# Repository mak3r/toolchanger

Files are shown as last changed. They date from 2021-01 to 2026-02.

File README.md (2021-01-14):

# E3D Toolchanger Experience

## Overview

The E3D toolchanger was one of the most excting announcements in the late 20-teens. I had been keeping my eyes on the project for some time as well as having a general interest in Core X/Y printing. 

The E3D Toolchanger is a specification and BOM for a 3D printer which can operate 4 different toolheads. In the past, we have seen dual extruder printers and even multi nozzle extruders. There have also been efforts to create multi filament processors leading to a single tool. These include the Palette and the Prusa MMU2s. My experience with these MMU2s multi filament processor was terrible. There seemed to be no scientific approach to tuning filament extraction which is absolutely necessary to achieve positive results. The Toolchanger does not suffer from this problem.

Since the toolchanger has 4 independent hotends, each one can be managed independently including filament load/unload/wipe/purge/prime operations. While it sounds like it might be 4x the complexity, I assure you it is not. The biggest challenge is tuning filaments but I have found other than using the parameters provided by the vendor - such as a Prusa MK3s with PrusaSlicer configs - the problem is universal.

Multi tool additive manufacturing for the hobbyist also became possible in part because of microprocessor development specifically for the multi-toolhead use case. The Toolchanger uses the Duet and Duex boards from Duet3D. These 32 bit boards have more motor driver capabilities as well as taking advantage of hardware based tool changes. I like this.

## What to expect if you are building a toolchanger

* Poor documentation
    * Steps out of order
    * Limited cleanups/revisions long after an issue has been identified
    * I actually stopped giving credit to the guide authors because the docs were so poorly done. 
    * On the other hand, this would have been impossible without the guides.
* Exactly the parts needed 
    * Sometimes less
* Print your own parts (you NEED another 3D printer to build this one)
* Additional tools required
    * locktite
    * superglue
    * 7mm wrench (nozzle)
    * 16mm slim wrench (tightening V6 nozzles)
    * 12mm slim wrench (putting on feet)
    * 2.5mm tap
    * 3mm tap

# Tips

## Mesh compensation
The system uses the G29 command to run mesh compensation:

* Run mesh compensation 
    
    `G29 S0`
* Save the last mesh comp values in a file called "abc.mesh"
    
    `G29 S3 P"abc.mesh"`
* Enable mesh compensation using the last saved mesh "heightmap.csv" (default name)
    
    `G29 S1`
* Disable mesh compensation
    
    `G29 S2`
    
## Tool Changes

The T commands are used for selecting tools. 

* Select no tool

	`T-1`
* Select a tool (make it active) but don't pick it up

	`T<toolnum> P0`
	
* Activate and pickup a tool

	`T<toolnum>`

### Caution

It is possible to get your printer into a state that is mechanically non-functional. Generally you will find a creative way to reset the system but there is not a simple logical solution in the software to recover. 

An example of this is if you were to power down or halt the printer because you see your tool is going to crash into the side of the bed. When you restart the printer, the tool is still attached but the axes and the coupler are not homed. You will very carfully need to figure out how to unlock the coupler while holding onto the tool so it doesn't fall and break something.
    
# Credits
* PrusaSlicer texture and model files in the [PrusaSlicer](PrusaSlicer) directory from [Paul Arden](https://forum.e3d-online.com/threads/prusaslicer-bed-svg-and-stl.3857/)

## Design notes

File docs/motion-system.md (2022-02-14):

# Procedures to test motion system is functional
These procedures should all be done individually and when in full view of the machine. These tests require human validation of successful outcomes.

## Normal motion test
Carefully insure all axis are homing properly and the resulting X,Y and Z settings accurately reflect safe movement under normal usage.

1. Home Y axis
    1. Insure tool dock stops movement when endstop triggers
    1. Insure tool dock moves away from stop
1. Home X axis
    1. Insure tool dock stops movement when endstop triggers
    1. Insure tool dock moves away from stop
1. Home C (lock/unlock)
    1. Insure tool dock locks then unlocks
1. Home Z
    1. Check Z probe homes to center
    1. Check that z-probe causes bed to stop
    1. Check that z axis moves slightly away from the probe after detection

## High speed tests
After checking each axis independently, attempt to home all axis using the programmatic homeall.g gcode file

1. HomeAll (should execute the homeall.g file)
    * Equivalent to  `M98 P"homeall.g"`
    1. Insure tool dock retreats to "out of the way" position"
    1. Insure bed is not too close to probe

## Also check

1. x/y belts are not slipping
    1. Set x and y axis to have a low Svalue for allowed slippage
        * `M915 X Y S-20 F0 H400`
    1. Move tool dock in x/y axis to test slippage is recognized. 
        * TODO: Create x/y rapid motion test as a macro
    1. Return slippage value to known working default. 
        * Currently: `M915 X Y S5 F0 H400`
    1. Move tool dock in x/y axis again to test slippage is not happening
        * TODO: Create x/y rapid motion test as a macro

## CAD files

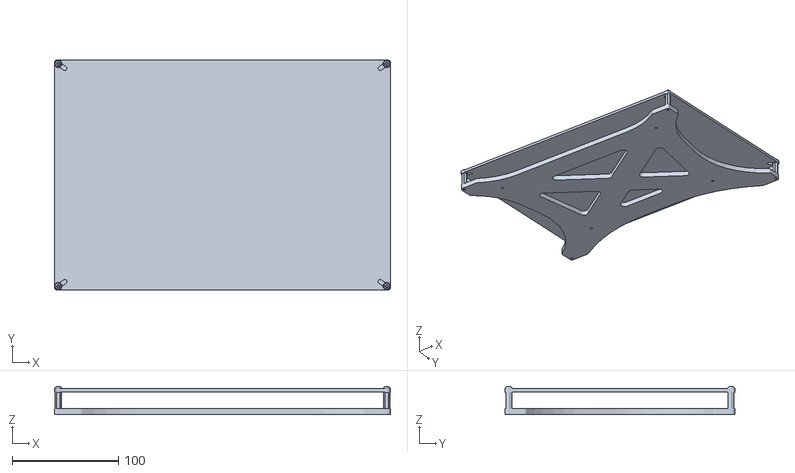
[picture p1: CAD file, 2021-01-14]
PrusaSlicer/e3d_toolchanger_bed.stl
316.0 x 216.0 x 26.7

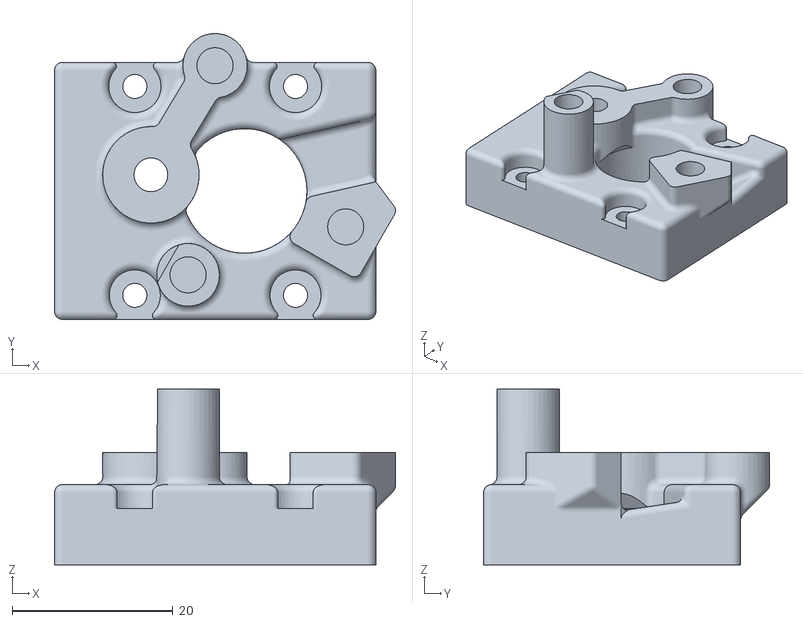
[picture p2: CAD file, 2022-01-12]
zesty/Nimble_V3_Flex_ToolChanger_Mount_Block.stl
42.4 x 35.6 x 21.9

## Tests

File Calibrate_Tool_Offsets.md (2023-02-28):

# Calibrate Z offset
Based on youtube video by Rene Jurack https://www.youtube.com/watch?v=XzVNxBuDcTc

1. Home All 
1. Level the bed
1. Calibrate Z
1. Calibrate XY

## Level the bed

### Set a smaller grid for probing
1. Change to a 4 point grid using the M557 command (speeds up the process)
1. `M557 X10:290 Y20:180 S<diff in x>:<diff in y>`
1. Take the original command from sys/config.g and change it accordingly
1. Enter this command in the command bar at the top of DWC

### Probe and adjust
1. `Dashboard`->`Compensation and Calibration`-> `True Bed Leveling (G32)`
1. Adjust the bed
1. Repeat until level

## Calibrate Z Offset
Note: calibration should take place at the same point on the bed that the probe uses for Z homing. A macro called `move_to_middle` has been created for this purpose. **MAKE SURE THE BED IS LOWERED ENOUGH SO THE TOOL DOES NOT COLLIDE INTO THE BED**

1. Heat up all tools and the bed
1. Select the tool `T<toolnum>` and `move_to_middle`
1. Use a business card or piece of paper about .2 mm thick
1. Adjust based on the known tool offset
1. For the selected tool, copy the `G10 ..` command from `sys/config.g`
1. Paste the command into the command bar at the top of DWC
1. Lay down the business card.
1. Move the nozzle closer to the bed until it just grabs the business card
1. Adjust the Z parameter of the G10 command using the  following formula
	
	* Z-off.old - (Z-pos.gui - Z-pos.real) = Z-off.new
	* where the real position is the business card thickness

1. Send the G10 command with the new Z-off.new position and the GUI should reflect the Z height is equal to the business card thickness when done properly
1. When the Z offset is correct, replace the command in the `sys/config.g` with the new Z offset

## Calibrate XY Offset
For this you will need a microscope or web cam temporarily mounted on the bed to get the tool x/y position offsets. Use T0 as the reference offset.

1. Lower the bed
1. Attach microscope
1. Select tool T0 - be sure it is above the microscope
1. Using DWC, Move tool so that the nozzle is centered over the microscope - zoom in with Z 
1. Make fine adjustments as needed in DWC
1. Jot down the current X and Y coordinates shown in DWC
1. Update the G1 command macros/move-to-microscope
	* Note the first G1 command has the move offsets just slightly off from the actual values
	* that were jotted down. The difference is a only
	* by about 1mm or so just to insure that it moves when triggering the macro

### Prepare the next tool offset
1. Select the tool offset command (G10) from the tool offsets section of sys/config.g
1. Paste and run that command in DWC
1. Select the Tool to configure (e.g. T1)
1. Run the macros/move-to-microscope command
1. Keep track of fine tuning x and y adjustments as you make them
1. Subtract the adjusted values from the original tool offset for each axis
1. Run the macros/move-to-microscope command
1. You should see the camera move off the center and back to it
	* if not, re-adjust
1. Copy the command from DWC back to the sys/config.g file for that tool offset
1. Repeat for next tool

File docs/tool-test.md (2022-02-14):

# Procedures to test a tool is fully functional

Most procedures refer to Hotend tools (extruding and melting plastics). Procedures for the heatbed are listed at the end of this file.

## Idle / cold test
When machine turns on

1. Extruder reports room temperature without a large variance
1. Hot end fan is off
1. Part cooling fan is off
1. Extruders are idle
1. All tools are deselected

## Functional evaluation

1. Hot end fan turns on when temperature reaches threshold set in M106 command
1. Heat raises to 100° and holds
1. Heat raises to 200° and holds
1. Heat raised to 280° and holds
1. Heat rased to 301° triggers fault per M143 command
1. Heat set to 0° causes hotend to return to room temperature

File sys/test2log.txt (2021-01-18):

2021-01-07 06:11:50 Event logging started
2021-01-07 06:15:24 HTTP client 192.168.86.54 login succeeded
2021-01-07 06:17:23 HTTP client 192.168.86.54 login succeeded
2021-01-07 06:19:25 HTTP client 192.168.86.54 login succeeded
2021-01-07 06:26:02 Started printing file 0:/gcodes/toolchange_test.gcode
2021-01-07 06:26:32 Error: G29: Height map file heightmap.csv not found
2021-01-07 06:26:39 Error: G29: Height map file heightmap.csv not found
2021-01-07 06:26:47 Error: G29: Height map file heightmap.csv not found
2021-01-07 06:26:54 Error: G29: Height map file heightmap.csv not found
2021-01-07 06:26:57 Error: Temperature reading fault on heater 4: sensor open circuit
2021-01-07 06:26:58 Resume state saved
2021-01-07 06:26:59 Printing paused at X304.5 Y175.0 Z62.0 C123.0
2021-01-07 06:27:41 Error: Attempting to extrude with no tool selected.
2021-01-07 06:27:45 Printing resumed
2021-01-07 06:27:45 Error: Bad command: X150 Y-49 F50000	
2021-01-07 06:27:45 Finished printing file 0:/gcodes/toolchange_test.gcode, print time was 0h 1m
2021-01-07 06:31:26 HTTP client 192.168.86.54 disconnected
2021-01-07 06:31:28 HTTP client 192.168.86.54 login succeeded
2021-01-07 06:33:24 HTTP client 192.168.86.54 login succeeded
2021-01-07 06:35:23 HTTP client 192.168.86.54 login succeeded
2021-01-07 06:36:16 Warning: VIN under-voltage event (9.5V)

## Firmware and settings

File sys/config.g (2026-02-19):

; Configurat; Configuration file for Duet WiFi / Ethernet
; executed by the firmware on start-up
; Configured for RepRapFirmware v3.x

; General preferences
M111 S0 						; Debugging off
G21 							; Work in millimetres
G90 							; Send absolute coordinates...
M83 							; ...but relative extruder moves
M555 P2 						; Set firmware compatibility to look like Marlin

; Network
; Read https://duet3d.dozuki.com/Wiki/Gcode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
M540 P48:E7:DA:1D:F8:B4 ;Set MAC address - 48:E7:DA:1D:F8:B3 was the default and conflicts with Roomba
M550 P"Mak3rs ToolChanger" 	; Set machine name
M552 S1	P192.168.86.8					  ; Enable Networking
M586 P0 S1 						; Enable HTTP
M586 P1 S0 						; Disable FTP
M586 P2 S0 						; Disable Telnet

M669 K1 						; Select CoreXY mode (RRF >= v2.0.3)

; NOTE: 584 Remains unchanged for Duet 2 board with RRF3
M584 X0 Y1 Z2 C7 E3:4:5:6 				; Apply custom drive mapping


; Endstops
M574 X1 S1 P"xstop"						; Set X endstop switch
M574 Y1 S1 P"ystop"						; Set Y endstop switch

M574 Z0 P"nil" ; no Z endstop switch, free up Z endstop input
M558 P5 C"zstop" H3 F360 I0 T20000		; Set Z probe type to switch, dive height and speeds
G31 P200 X0 Y0 Z0	 				; Set Z probe trigger value, offset and trigger height
M557 X10:290 Y20:180 S40 				; Define mesh grid


; Drive direction
M569 P0 S0 						; Drive 0 X
M569 P1 S0 						; Drive 1 Y
M569 P2 S1 						; Drive 2 Z
M569 P3 S1 						; Drive 3 E0
M569 P4 S1 						; Drive 4 E1
M569 P5 S1 						; Drive 5 E2
M569 P6 S1 						; Drive 6 E3
M569 P7 S0 						; Drive 7 COUPLER
M569 P8 S0 						; Drive 8 UNUSED
M569 P9 S0 						; Drive 9 UNUSED

M208 X-29:332 Y-45.8:242.5 Z0:300 C0:260 S0 		; Set axis maxima & minima
M350 C8 I0 					                        ; Configure microstepping without interpolation
M350 X16 Y16 Z16 E16:16:16:16 I1					; Configure microstepping with interpolation
M92 X100 Y100 Z1600 C100 E2780:2780:2780:397		    ; Set steps per mm
M566 X400 Y400 Z8 C2 E40:40:40:2				        ; Set maximum instantaneous speed changes (mm/min)
M203 X35000 Y35000 Z1200 C5000 E2400:2400:2400:5000	; Set maximum speeds (mm/min)
M201 X6000 Y6000 Z400 C400 E120:120:120:2500		; Set accelerations (mm/s^2)
M906 X2000 Y2000 Z1330 C400 E700:700:700:798 I30 	; Set motor currents (mA) and motor idle factor in percent
M84 S120 												; Set idle timeout

;Stall Detection
M915 C S5 F0 H200 					; Coupler

;Stall Detection
M915 X Y S10 F1 R2 H400              ; X / Y Axes, sensitivity 10, filtered, pause

; ***************************************
; Sensors M308
; Asscociated with Heaters M950

; HEAT BED ;
M140 H0                             ; Declare bed heater 0 exists
M308 S0 P"bedtemp" Y"thermistor" A"Bed" T100000 B4725 C7.06e-8	;Heat bed thermistor
M950 H0 T0 C"bedheat"				; Associate heater with thermistor
M143 H0 S225 						; Set temperature limit for heater 0 to 225C

; EXTRUDER 0 ;
M308 S1 P"e0temp" Y"thermistor" A"T0" T100000 B4725 C7.06e-8	;E0 thermistor
M950 H1 T1 C"e0heat"				; Associate heater with thermistor
M143 H1 S300 						; Set temperature limit for heater 1 to 300C

; EXTRUDER 1 ;
M308 S2 P"e1temp" Y"thermistor" A"T1" T100000 B4725 C7.06e-8	;E1 thermistor
M950 H2 T2 C"e1heat"				; Associate heater with thermistor
M143 H2 S300 						; Set temperature limit for heater 2 to 300C

; EXTRUDER 2 ;
M308 S3 P"duex.e2temp" Y"thermistor" A"T2" T100000 B4725 C7.06e-8	;E2 thermistor
M950 H3 T3 C"duex.e2heat"
M143 H3 S300 						; Set temperature limit for heater 3 to 300C

; EXTRUDER 3 ;
M308 S4 P"duex.e3temp" Y"thermistor" A"T3" T100000 B4725 C7.06e-8	;E3 thermistor
M950 H4 T4 C"duex.e3heat"
M143 H4 S300 						; Set temperature limit for heater 4 to 300C


; Tools
M563 P0 S"T0" D0 H1 F2 					; Define tool 0
G10 P0 X0 Y0 Z0 					; Reset tool 0 axis offsets
G10 P0 R0 S0 						; Reset initial tool 0 active and standby temperatures to 0C

M563 P1 S"T1" D1 H2 F4					; Define tool 1
G10 P1 X0 Y0 Z0 					; Reset tool 1 axis offsets
G10 P1 R0 S0 						; Reset initial tool 1 active and standby temperatures to 0C

M563 P2 S"T2" D2 H3 F6					; Define tool 2
G10 P2 X0 Y0 Z0 					; Reset tool 2 axis offsets
G10 P2 R0 S0 						; Reset initial tool 2 active and standby temperatures to 0C

M563 P3 S"T3" D3 H4 F8					; Define tool 3
G10 P3 X0 Y0 Z0 					; Reset tool 3 axis offsets
G10 P3 R0 S0 						; Reset initial tool 3 active and standby temperatures to 0C

; ***********************************
; Fans
; M950 to create Fans
; M106 to set fan parameters

M950 F0 C"nil"					; Fan id 0 is unused
M106 P0 S0						; UNUSED


; Tool 0
M950 F1 C"fan1"					; T0 Hotend Fan
M106 P1 S255 H1 T70				; T0 HE
M950 F2 C"fan2"					; T0 Part Cooling Fan
M106 P2 S0						; T0 PCF

; Tool 1
M950 F3 C"duex.fan3"			; T1 Hotend Fan
M106 P3 S255 H2 T70 			; T1 HE
M950 F4 C"duex.fan4"			; T1 Part Cooling Fan
M106 P4 S0						; T1 PCF 

; Tool 2
M950 F5 C"duex.fan5"			; T2 Hotend Fan
M106 P5 S255 H3 T70 			; T2 HE 
M950 F6 C"duex.fan6"			; T2 Part Cooling Fan
M106 P6 S0 						; T2 PCF

; Tool 3
M950 F7 C"duex.fan7"			; T3 Hotend Fan
M106 P7 S255 H4 T70				; T3 HE
M950 F8 C"duex.fan8"			; T3 Part Cooling Fan
M106 P8 S0						; T3 PCF

M593 F50						; cancel ringing at 50Hz (https://forum.e3d-online.com/threads/accelerometer-and-resonance-measurements-of-the-motion-system.3445/)
;M376 H15						; bed compensation taper

;tool offsets
; !ESTIMATED! offsets for:
; V6-tool: X-9 Y39 Z-5
; Volcano-tool: X-9 Y39 Z-13.5
; Hemera-tool: X-37.5 Y43.5 Z-6
; Revo Micro: X-9 Y39 Z-5

G10 P0 X-9 Y39 Z-4.71					; T0
G10 P1 X-9.6 Y39.4 Z-4.73				; T1
G10 P2 X-9.34 Y39.22 Z-4.78				; T2
G10 P3 X18.6 Y43.66 Z-5.95			    ; T3

;deselect tools
T-1

; Pressure Advance
; Only considered for bowden tools
;M572 D0 S0.2 						; pressure advance T0
;M572 D1 S0.2 						; pressure advance T1
;M572 D2 S0.2 						; pressure advance T2
;M572 D3 S0.2 						; pressure advance T3

; Initialize max bedtemp variable
; This is used to allow filament config files to defer to the highest 
; Bed temperature for all active tools
; @call: max-bed-temp within the filament config.g
; @see: max-bed-temp.g
; @example: M98 P"max-bed-temp.g" S<temp>
global max_bedtemp=0

; RRF v3.5+
; Initialize filament types
; represent the filament names for each extruder
; Initialize each one to NONE and then set the filament type (ftype)
;  in the filaments/<filament>/config.g file
; Use the filament type when prime/purge
;global ftype={NONE,NONE,NONE,NONE}

M501; load config-override.g

; Interfaces
; Paneldue
M575 P1 B57600 S1

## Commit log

2021-01-09 initial configs
    [config.g]
2021-01-09 enable nozzle prime procedure for T0 and T1
    [tpost0.g, tpost1.g]
2021-01-11 script updates
    [prime2.g, tpre2.g]
2021-01-14 updated config bundle, updated README, added bed image for slicer
    [e3d_toolchanger_bed.stl]
2021-01-18 sys configs
    [prime2.g, prime_v6.g, tpost2.g]
2021-01-18 include all sys configs, not just changed ones
    [bed.g, brush.g, cancel.g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]
2021-01-18 some changes were not captured The prime_v6 changes in this version are actually filament specific The 'metallic' filament has some sort of property that causes it to retract itself The forces a long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
    [heightmap.csv, prime_v6.g, tpost0.g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]
2021-01-19 revert prime_v6
    [prime_v6.g]
2021-01-30 actual files in use on the toolchanger
    [bed.g, cancel.g, heightmap.csv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]
2021-02-02 calibrated and modified feedrates for T0,T1,T2
    [config.g]
2021-02-02 updated configs for infill speeds on .2mm quality @TC
2021-02-15 stock toolchange test and calibration gcodes
2021-02-16 calibrated T0,T1,T2
    [config.g]
2021-02-28 re-calibrated tools and offsets
    [config.g, tpre0.g]
2021-02-28 adjust T0 X offset
    [tfree0.g]
2021-03-12 physical endstops and tool pickup adjustments
    [config.g, homex.g, homey.g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]
2021-03-15 use G53 when locating tools
    [config.g, homeall.g, tfree0.g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]
2021-03-16 update primes and set CoreXY mode for RRF >=v2.0.3
    [config.g, primeT0.g, primeT1.g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]
2021-03-17 x/y offset calibrations
    [config.g, pause.g, tfree0.g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]
2021-04-19 filaments loads/unloads macros, update config for a leveler bed
    [Load PETG.g, Load PLA.g, Unload PETG.g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]
2021-05-12 filament configurations Added tool unique filament options. Created zip archive of nylon filament for easy upload Added config.g for firmware overrides necessary for nylon Added M703 command to tpost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
    [config.g, load.g, tpost0.g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]
2021-05-23 updated filament configs
    [config.g, load.g, unload.g]
2022-01-12 Xy switched endstops (#2)
    * added stl for zesty nimble attachement
    * update filaments and priming
    * snapshot of toolchanger sys
    * filaments direct from the toolchanger
    * macros ported direct from toolchanger
    [20210206.csv, 20210316.csv, 20210411.csv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]
2022-02-14 Initial configuration required to use RRF 3.x (#3)
    * updated thermistor and heater commands 308 and 950.
    Re-enabled thermistor and heater for tool 4
    * Explicitly add fans.
    Re-enable fans for Tool 3 which is now installed
    * z probe updated command M558
    * x and y endstops M574
    * update all known format changes from RRF 2 to 3 in existing gcode
    * starting to build out more comprehensive documentation
    * updated xyz axis homing
    * updated with additional motion system testing
    * update motion system content
    * cleanup home(x/y/z) files
    * reset maxima and minima
    * update motion configs
    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
    [bed.g, cancel.g, config.g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]
2022-02-14 increase motor current to 700mA This gives faster speeds over longer durations F1800 ~30mm/s seems to be the top speed for very long runs - such as load and unload operations
    [config.g]
2022-02-15 reduced steps / mm
    [config.g]
2022-02-15 declare bed heater
    [config.g]
2022-02-15 New PLA filament config for T0 with Zesty Nimble
    [config.g, load.g, unload.g]
2022-02-16 refinements after RRF v3.x upgrade Updated motor current and steps for T3 (Hemera) tpre0 had unmerged merge details and is fixed tpost0 and tpost3 were updated to load filaments config.g first and th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
    [config.g, load.g, tpost0.g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]
2022-03-03 filaments updates
    [config.g, load.g, unload.g]
2022-03-03 tool z offsets
    [config.g]
2022-03-03 update pause location away from the tool side
    [pause.g]
2022-03-03 update prime and post routines according to current tool needs
    [primeT0.g, primeT2.g, primeT3.g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]
2022-06-15 config updates for non-bowden tools
    [config.g, load.g, unload.g]
2022-08-03 updated filament configs for zesty
    [config.g, load.g, unload.g]
2022-08-03 correct bed temp. correct load thru
    [config.g, load.g]
2022-11-21 configs on tc pre-mods to T1 and T2 add zestys
    [config.g, filaments.csv, heightmap.csv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]
2022-11-23 configuration updates: filament configs for all tools pla. alignments for all tools x,y,z due to tool mods including adding zesty nimbles to T1 and T2.
    [config.g, load.g, max-bed-temp.g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]
2022-12-19 fix load filament custom config for T1
    [tpost1.g]
2022-12-22 updates post RRF v3.4 upgrade
    [config.g, filaments.csv, heightmap.csv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]
2022-12-22 filament updates
    [20210206.csv, 20210316.csv, 20210411.csv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]
2023-02-28 updated filaments and docs on calibration
    [config.g, load.g, primeT1.g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]
2023-02-28 various changes after nimble and revo upgrades
    [config.g, filaments.csv, primeT2.g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]
2023-06-28 updated for zesty nimbles
    [config.g, load.g, unload.g]
2024-03-03 2024-03-03 live configuration
    [config-override.g, config.g, filaments.csv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]
2024-03-05 updated tool offsets T0 hotend is now a revo micro T1 hotend is now a revo micro
    [config.g]
2026-02-19 cleanup filaments dir
    [config.g, filaments.csv, heightmap.csv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]
